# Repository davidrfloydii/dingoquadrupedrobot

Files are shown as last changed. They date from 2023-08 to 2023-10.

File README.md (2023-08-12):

# dingoquadrupedrobot
Modifications to Dingo Quadruped Robot

## [KiCAD PCB](https://github.com/davidrfloydii/dingoquadrupedrobot/tree/main/PCB)
Since the original files were Altium designer I recreated the board in KiCAD. Not 100% the same since it uses through hole components for the resistors and the diode.
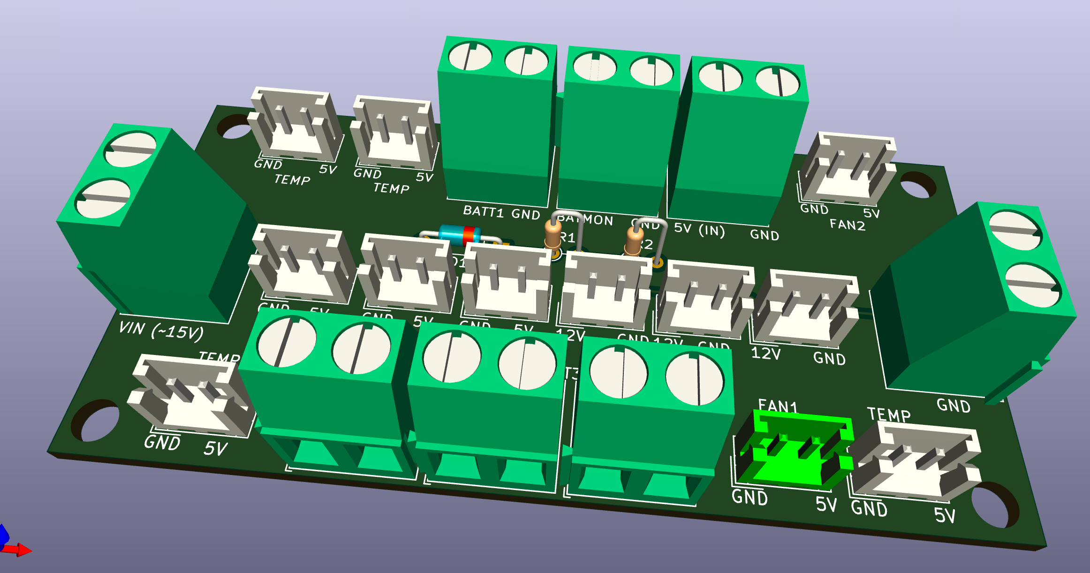
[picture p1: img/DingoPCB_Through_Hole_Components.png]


## [Modified Base Plate](https://github.com/davidrfloydii/dingoquadrupedrobot/blob/main/CAD/Dingo%20Base%20Plate.step)
Instead of ordering the Acrylic pieces you can try to print your own base plates. **Note**: This is not verified to hold up to the stresses of the robot. However if you decide to go this route be sure to use 100% infill for these pieces. Also blue the two halves together. Since it is printed this will have stand offs for 2 of the Raspberry Pi mounts and the rear of the front buck converter.
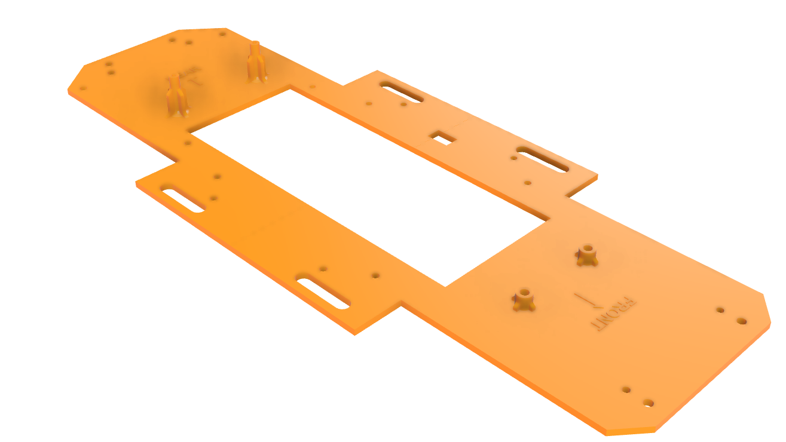
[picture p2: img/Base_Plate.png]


## [Redesigned LCD Bracket](https://github.com/davidrfloydii/dingoquadrupedrobot/blob/main/CAD/Rear%20LCD%20Holder%20v1.step)
For my build I decided to redesign the rear LCD holder so that screws and nuts weren't positioning. **Note** This still has not been tested and results may vary depending on your printer settings.
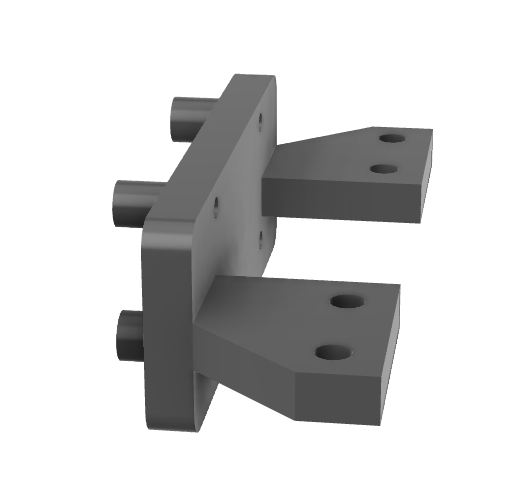
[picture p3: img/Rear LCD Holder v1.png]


## [New nose piece](https://github.com/davidrfloydii/dingoquadrupedrobot/blob/main/CAD/Dingo%20Front%20With%20Sonar%20v1.step)
The first modificaiton was to the front of the Dingo robot, it removes the plastic black eye and instead makes room for two HC-SR04 sensors.
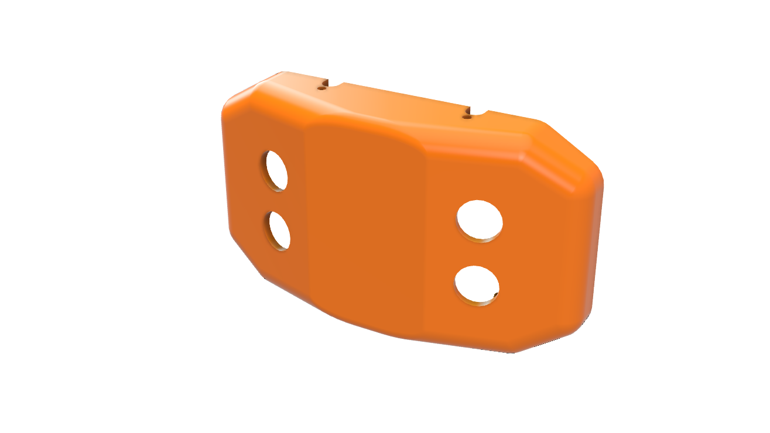
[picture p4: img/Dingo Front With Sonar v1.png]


## [New Fan Housing](https://github.com/davidrfloydii/dingoquadrupedrobot/blob/main/CAD/Fan%20Housings%20Builtin%20Hinge%20Pins.step)
This new fan housing creates tabs to act as the hinge. Reduces the number of pieces that need to be ordered.
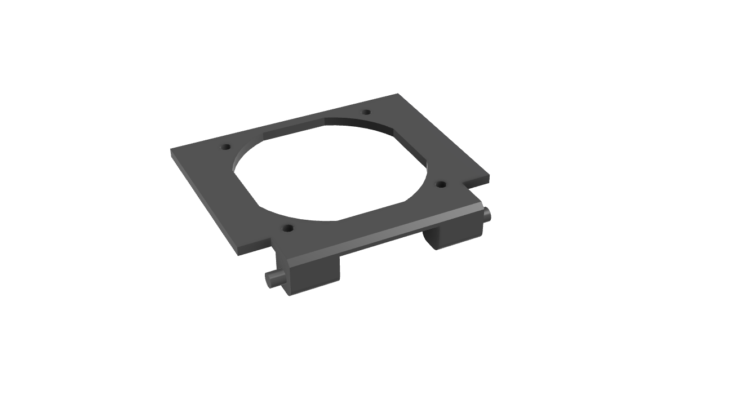
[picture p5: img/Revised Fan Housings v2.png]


## [Revised IMU Mount]((https://github.com/davidrfloydii/dingoquadrupedrobot/blob/main/CAD//Revised%20IMU%20Mount%20v4.step)
I updated the IMU mount because the version I ordered here in the US had slightly different pattern for mounting holes. Additionally the 3 digit display I ordered from Amazon also had slightly different mounting holes. If you are using the same components you can use this step file.
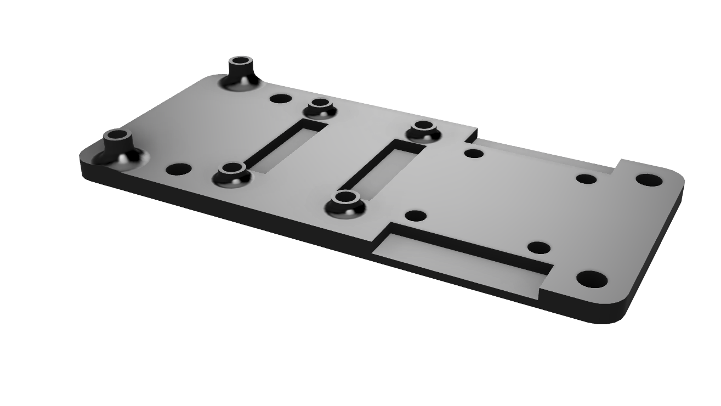
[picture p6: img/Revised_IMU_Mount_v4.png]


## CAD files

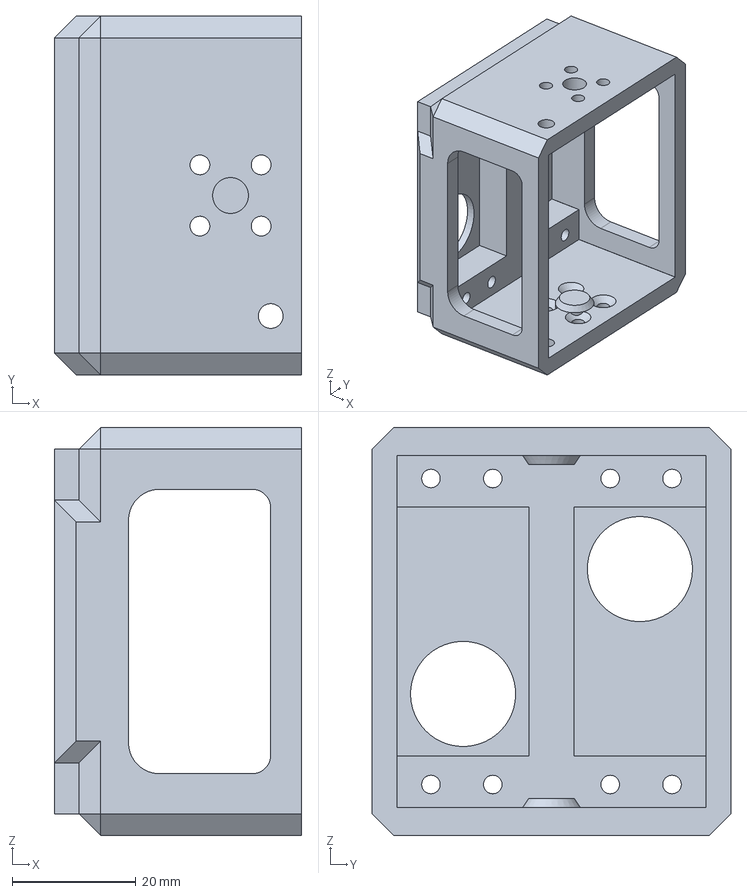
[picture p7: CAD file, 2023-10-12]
CAD/Modified Servo Carriers 01.step
40.0 x 58.0 x 66.0 mm

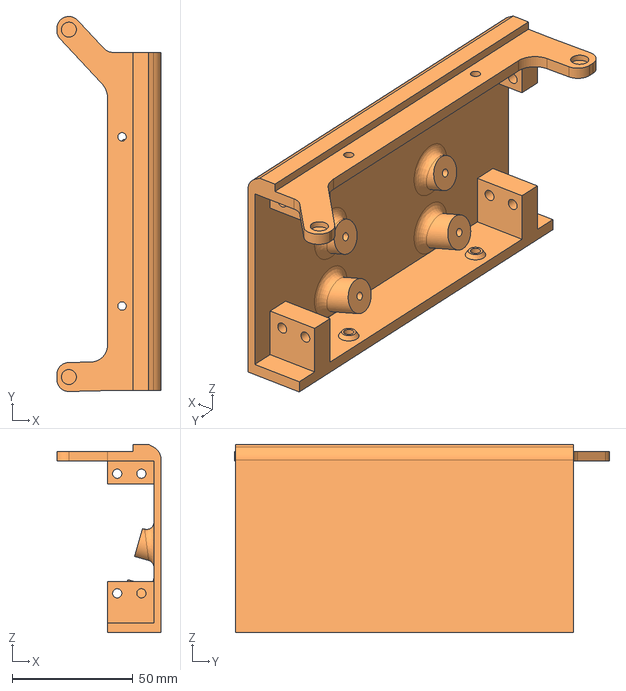
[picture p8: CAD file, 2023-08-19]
CAD/Revised Support PCA9685.step
43.2 x 155.2 x 77.9 mm

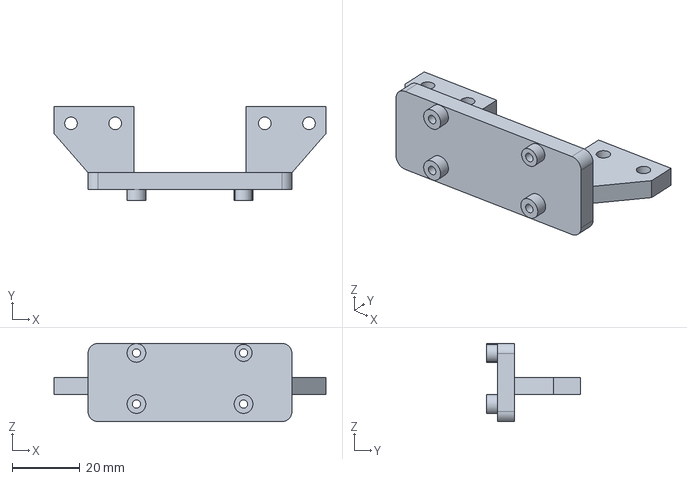
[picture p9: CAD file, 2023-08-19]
CAD/Rear LCD Holder.step
80.0 x 27.8 x 23.0 mm

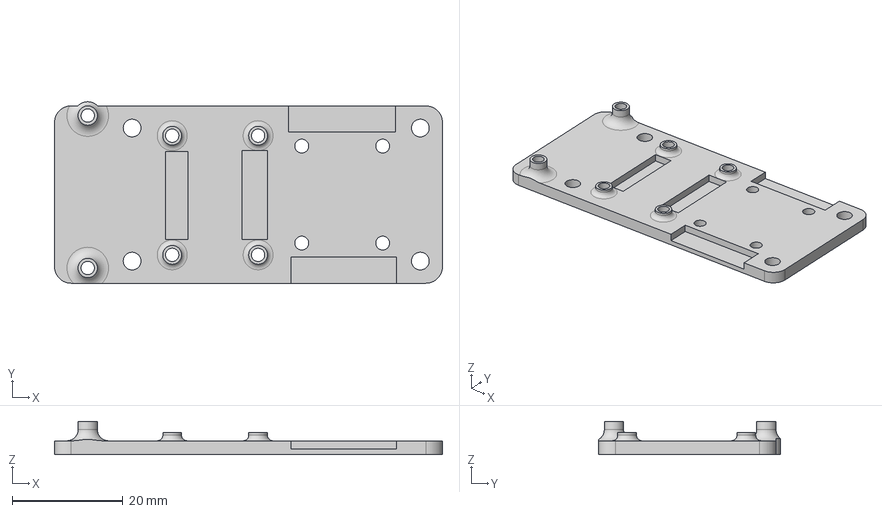
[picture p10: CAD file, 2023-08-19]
CAD/Revised IMU Mount.step
70.0 x 32.7 x 6.00 mm

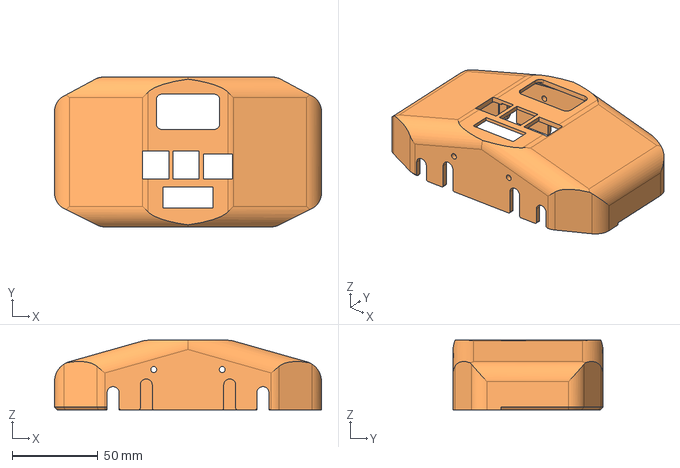
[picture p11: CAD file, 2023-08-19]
CAD/Joined Rear Housing.step
156.0 x 87.5 x 40.6 mm

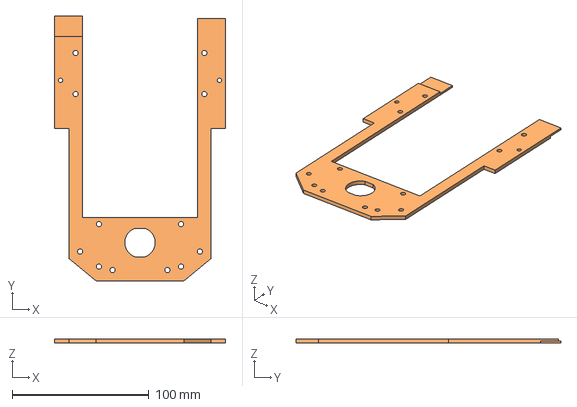
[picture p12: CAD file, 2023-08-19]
CAD/Revised Top Plate 02.step
125.0 x 193.5 x 3.00 mm

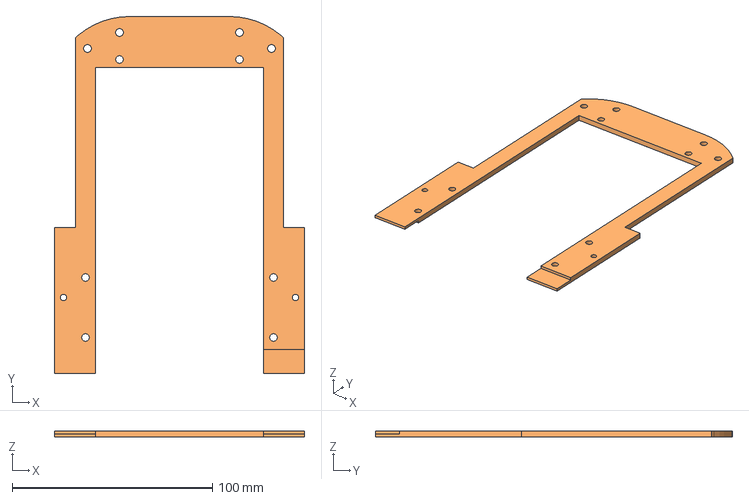
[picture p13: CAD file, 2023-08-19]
CAD/Revised Top Plate 01.step
125.0 x 178.5 x 3.00 mm

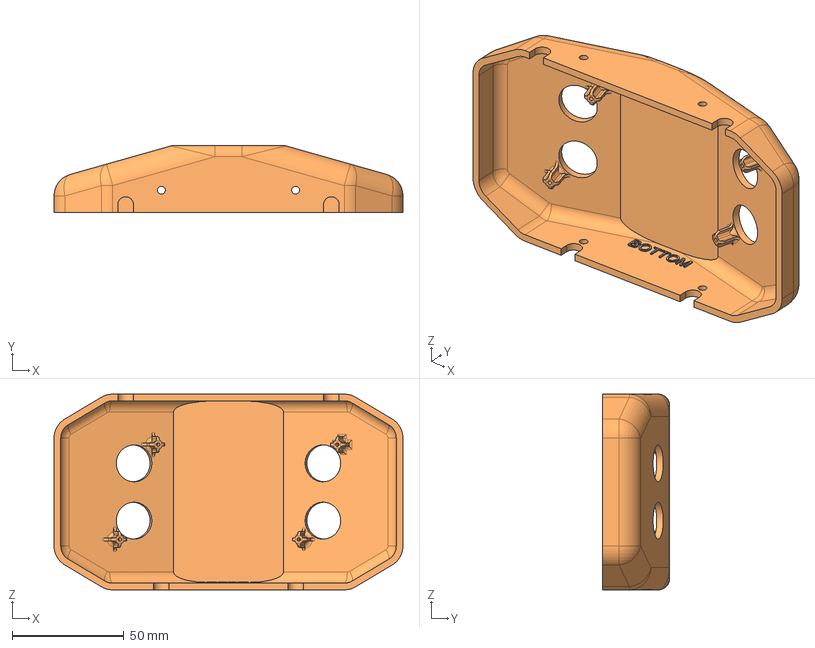
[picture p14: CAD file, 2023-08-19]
CAD/Dingo Front With Sonar.step
156.0 x 30.0 x 87.5 mm

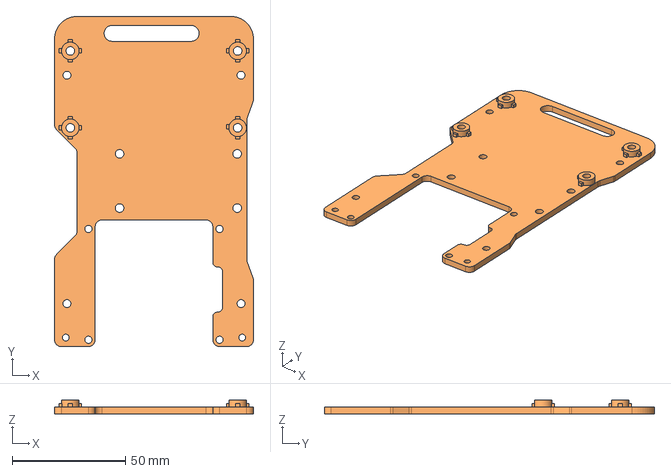
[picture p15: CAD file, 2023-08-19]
CAD/Revised Board Support.step
88.0 x 146.0 x 6.00 mm

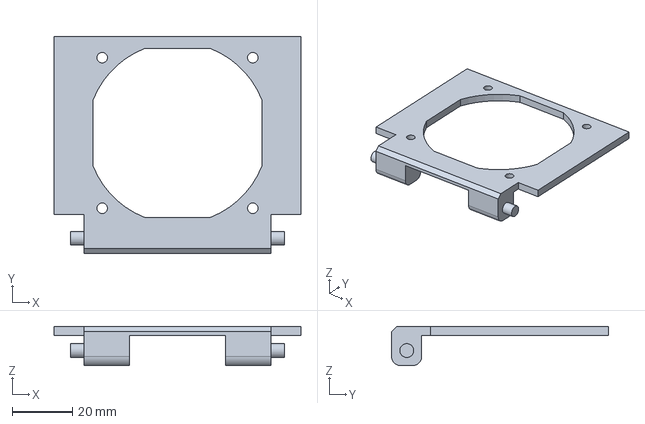
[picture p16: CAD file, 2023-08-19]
CAD/Revised Fan Housings.step
82.0 x 72.0 x 13.0 mm

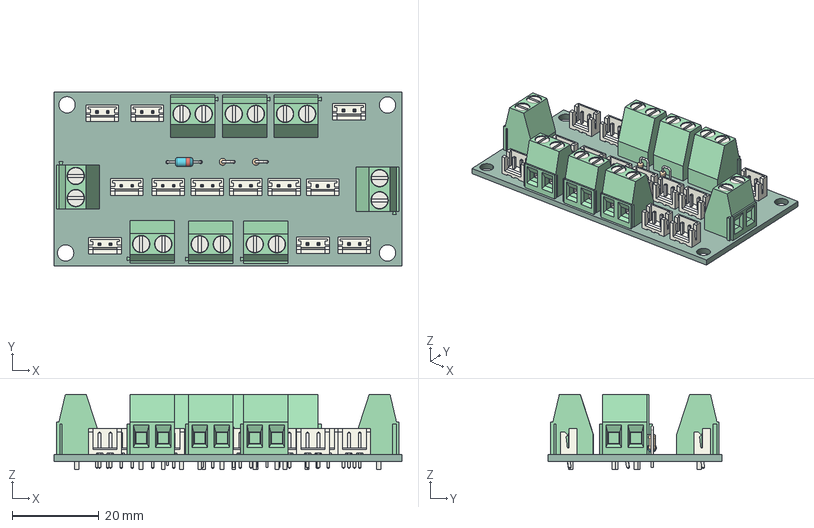
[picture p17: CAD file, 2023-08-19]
CAD/DingoPCB.step
80.0 x 40.0 x 17.3 mm
PCB

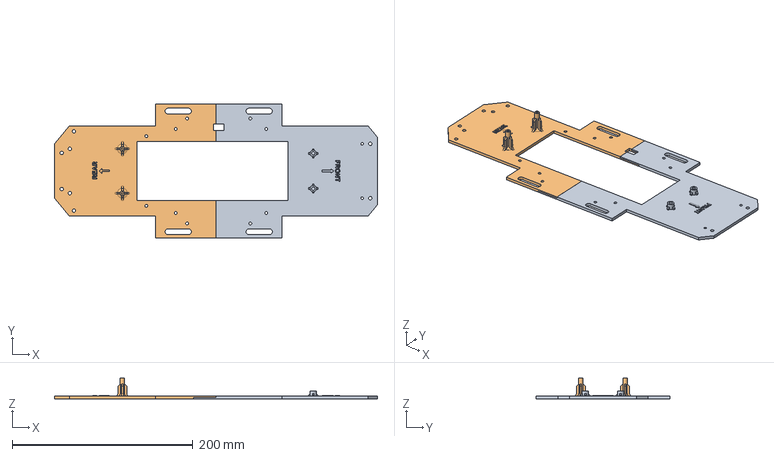
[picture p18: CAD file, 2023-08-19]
CAD/Dingo Base Plate.step
357.0 x 148.4 x 23.0 mm
Torso base plate
Back

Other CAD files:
CAD/Modified Servo Carriers 02.step
CAD/Fan Housings Builtin Hinge Pins.step
CAD/Revised IMU Mount v4.step
CAD/Rear LCD Holder v1.step

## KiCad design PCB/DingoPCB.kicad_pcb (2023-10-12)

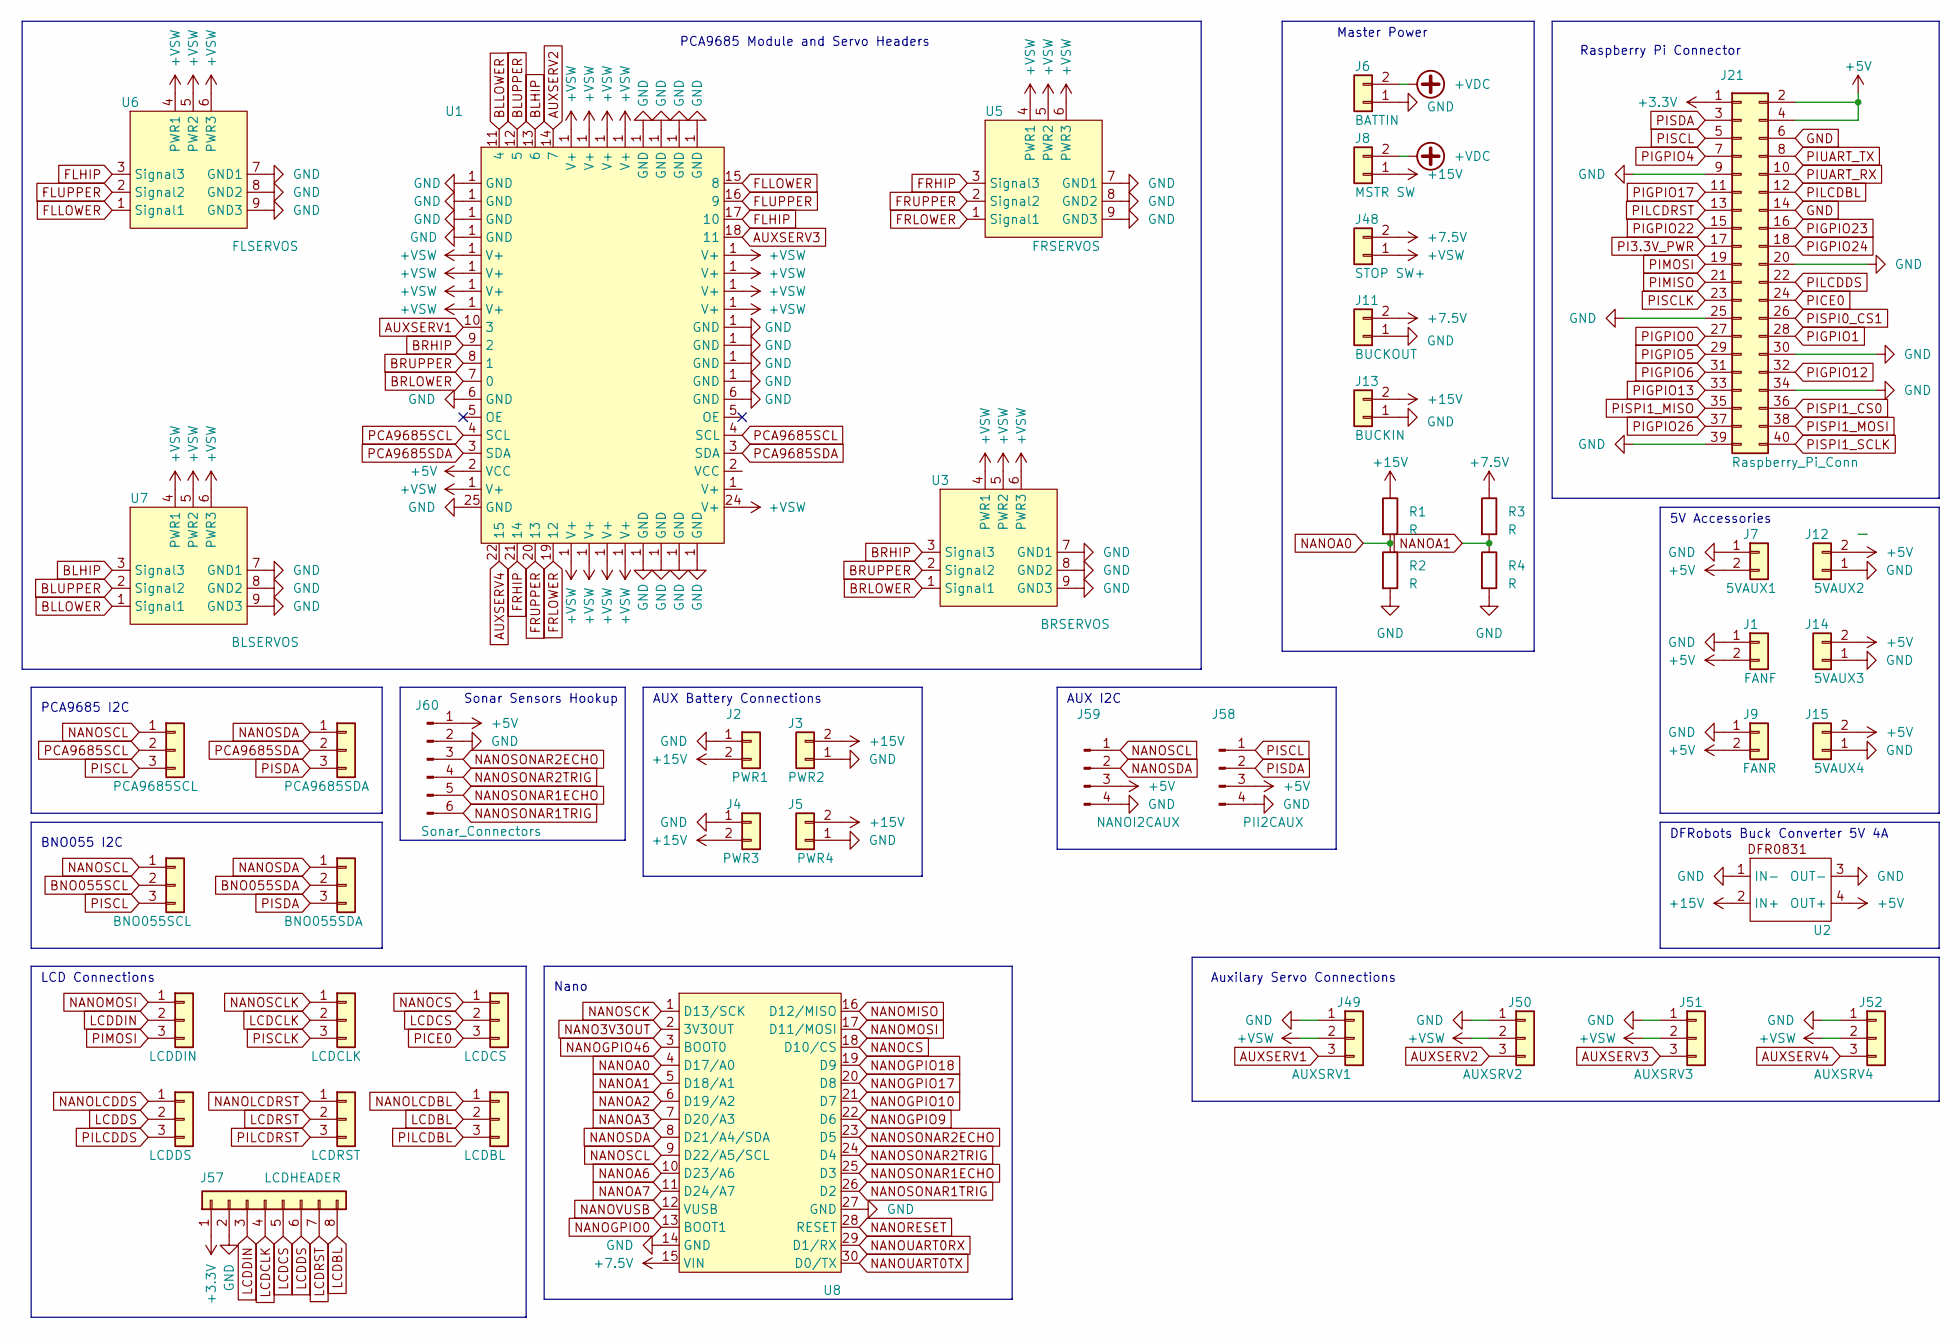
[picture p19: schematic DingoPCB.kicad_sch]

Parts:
J1: FANF; JST_EH_B2B-EH-A_1x02_P2.50mm_Vertical
J2: PWR1; TerminalBlock_Phoenix_MKDS-1,5-2-5.08_1x02_P5.08mm_Horizont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
J3: PWR2; TerminalBlock_Phoenix_MKDS-1,5-2-5.08_1x02_P5.08mm_Horizont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
J4: PWR3; TerminalBlock_Phoenix_MKDS-1,5-2-5.08_1x02_P5.08mm_Horizont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
J5: PWR4; TerminalBlock_Phoenix_MKDS-1,5-2-5.08_1x02_P5.08mm_Horizont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
J6: BATTIN; TerminalBlock_Phoenix_MKDS-1,5-2-5.08_1x02_P5.08mm_Horizont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
J7: 5VAUX1; JST_EH_B2B-EH-A_1x02_P2.50mm_Vertical
J8: MSTR SW; TerminalBlock_Phoenix_MKDS-1,5-2-5.08_1x02_P5.08mm_Horizont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
J9: FANR; JST_EH_B2B-EH-A_1x02_P2.50mm_Vertical
J10: PCA9685SDA; PinHeader_1x03_P2.54mm_Vertical
J11: BUCKOUT; TerminalBlock_Phoenix_MKDS-1,5-2-5.08_1x02_P5.08mm_Horizont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
J12: 5VAUX2; JST_EH_B2B-EH-A_1x02_P2.50mm_Vertical
J13: BUCKIN; TerminalBlock_Phoenix_MKDS-1,5-2-5.08_1x02_P5.08mm_Horizont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
J14: 5VAUX3; JST_EH_B2B-EH-A_1x02_P2.50mm_Vertical
J15: 5VAUX4; JST_EH_B2B-EH-A_1x02_P2.50mm_Vertical
J16: BNO055SDA; PinHeader_1x03_P2.54mm_Vertical
J17: BNO055SCL; PinHeader_1x03_P2.54mm_Vertical
J18: LCDDS; PinHeader_1x03_P2.54mm_Vertical
J19: LCDRST; PinHeader_1x03_P2.54mm_Vertical
J20: LCDBL; PinHeader_1x03_P2.54mm_Vertical
J21: Raspberry_Pi_Conn; PinHeader_2x20_P2.54mm_Vertical
J48: STOP SW+; TerminalBlock_Phoenix_MKDS-1,5-2-5.08_1x02_P5.08mm_Horizont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
J49: AUXSRV1; PinHeader_1x03_P2.54mm_Vertical
J50: AUXSRV2; PinHeader_1x03_P2.54mm_Vertical
J51: AUXSRV3; PinHeader_1x03_P2.54mm_Vertical
J52: AUXSRV4; PinHeader_1x03_P2.54mm_Vertical
J53: PCA9685SCL; PinHeader_1x03_P2.54mm_Vertical
J54: LCDDIN; PinHeader_1x03_P2.54mm_Vertical
J55: LCDCLK; PinHeader_1x03_P2.54mm_Vertical
J56: LCDCS; PinHeader_1x03_P2.54mm_Vertical
J57: LCDHEADER; PinHeader_1x08_P2.54mm_Horizontal
J58: PII2CAUX; JST_EH_B4B-EH-A_1x04_P2.50mm_Vertical
J59: NANOI2CAUX; JST_EH_B4B-EH-A_1x04_P2.50mm_Vertical
J60: Sonar_Connectors; JST_EH_B6B-EH-A_1x06_P2.50mm_Vertical
R1, R2, R3, R4: R; R_Axial_DIN0204_L3.6mm_D1.6mm_P2.54mm_Vertical
U1: Adafruit PCA9685 rev C
U2: DFR0831
U3: BRSERVOS; Three_Servo_Footprint
U5: FRSERVOS; Three_Servo_Footprint
U6: FLSERVOS; Three_Servo_Footprint
U7: BLSERVOS; Three_Servo_Footprint
U8: Arduino_Nano_ESP32

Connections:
+3.3V: J21.1, J57.1
+5V: J1.2, J7.2, J9.2, J12.2, J14.2, J15.2, J21.2, J21.4, J58.3, J59.3, J60.1, U1.2 (VCC), U2.4 (OUT+); also elsewhere on the board
+7.5V: J11.2, J48.2, R3.1, U8.15 (VIN)
+15V: J2.2, J3.2, J4.2, J5.2, J8.1, J13.2, R1.1, U2.2 (IN+)
+VDC: J6.2, J8.2
AUXSERV1: J49.3, U1.10 (3)
AUXSERV2: J50.3, U1.14 (7)
AUXSERV3: J51.3, U1.18 (11)
AUXSERV4: J52.3, U1.22 (15)
BLHIP: U1.13 (6), U7.3 (Signal3)
BLLOWER: U1.11 (4), U7.1 (Signal1)
BLUPPER: U1.12 (5), U7.2 (Signal2)
BNO055SCL: J17.2; also elsewhere on the board
BNO055SDA: J16.2; also elsewhere on the board
BRHIP: U1.9 (2), U3.3 (Signal3)
BRLOWER: U1.7 (0), U3.1 (Signal1)
BRUPPER: U1.8 (1), U3.2 (Signal2)
FLHIP: U1.17 (10), U6.3 (Signal3)
FLLOWER: U1.15 (8), U6.1 (Signal1)
FLUPPER: U1.16 (9), U6.2 (Signal2)
FRHIP: U1.21 (14), U5.3 (Signal3)
FRLOWER: U1.19 (12), U5.1 (Signal1)
FRUPPER: U1.20 (13), U5.2 (Signal2)
LCDBL: J20.2, J57.8
LCDCLK: J55.2, J57.4
LCDCS: J56.2, J57.5
LCDDIN: J54.2, J57.3
LCDDS: J18.2, J57.6
LCDRST: J19.2, J57.7
NANO3V3OUT: U8.2 (3V3OUT)
NANOA0: R1.2, R2.1, U8.4 (D17/A0)
NANOA1: R3.2, R4.1, U8.5 (D18/A1)
NANOA2: U8.6 (D19/A2)
NANOA3: U8.7 (D20/A3)
NANOA6: U8.10 (D23/A6)
NANOA7: U8.11 (D24/A7)
NANOCS: J56.1, U8.18 (D10/CS)
NANOGPIO0: U8.13 (BOOT1)
NANOGPIO9: U8.22 (D6)
NANOGPIO10: U8.21 (D7)
NANOGPIO17: U8.20 (D8)
NANOGPIO18: U8.19 (D9)
NANOGPIO46: U8.3 (BOOT0)
NANOLCDBL: J20.1
NANOLCDDS: J18.1
NANOLCDRST: J19.1
NANOMISO: U8.16 (D12/MISO)
NANOMOSI: J54.1, U8.17 (D11/MOSI)
NANORESET: U8.28 (RESET)
NANOSCK: U8.1 (D13/SCK)
NANOSCL: J17.1, J53.1, J59.1, U8.9 (D22/A5/SCL)
NANOSCLK: J55.1
NANOSDA: J10.1, J16.1, J59.2, U8.8 (D21/A4/SDA)
NANOSONAR1ECHO: J60.5, U8.25 (D3)
NANOSONAR1TRIG: J60.6, U8.26 (D2)
NANOSONAR2ECHO: J60.3, U8.23 (D5)
NANOSONAR2TRIG: J60.4, U8.24 (D4)
NANOUART0RX: U8.29 (D1/RX)
NANOUART0TX: U8.30 (D0/TX)
NANOVUSB: U8.12 (VUSB)
PCA9685SCL: J53.2, U1.4 (SCL)
PCA9685SDA: J10.2, U1.3 (SDA)
PI3.3V_PWR: J21.17
PICE0: J21.24, J56.3
PIGPIO0: J21.27
PIGPIO1: J21.28
PIGPIO4: J21.7
PIGPIO5: J21.29
PIGPIO6: J21.31
PIGPIO12: J21.32
PIGPIO13: J21.33
PIGPIO17: J21.11
PIGPIO22: J21.15
PIGPIO23: J21.16
PIGPIO24: J21.18
PIGPIO26: J21.37
PILCDBL: J20.3, J21.12
PILCDDS: J18.3, J21.22
PILCDRST: J19.3, J21.13
PIMISO: J21.21
PIMOSI: J21.19, J54.3
PISCL: J17.3, J21.5, J53.3, J58.1
PISCLK: J21.23, J55.3
PISDA: J10.3, J16.3, J21.3, J58.2
PISPI0_CS1: J21.26
PISPI1_CS0: J21.36
PISPI1_MISO: J21.35
PISPI1_MOSI: J21.38
PISPI1_SCLK: J21.40
PIUART_RX: J21.10
PIUART_TX: J21.8

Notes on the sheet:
Nano
PCA9685 I2C
5V Accessories
LCD Connections
AUX Battery Connections
PCA9685 Module and Servo Headers
AUX I2C
Sonar Sensors Hookup
Auxilary Servo Connections
Master Power
BNO055 I2C
DFRobots Buck Converter 5V 4A
Raspberry Pi Connector

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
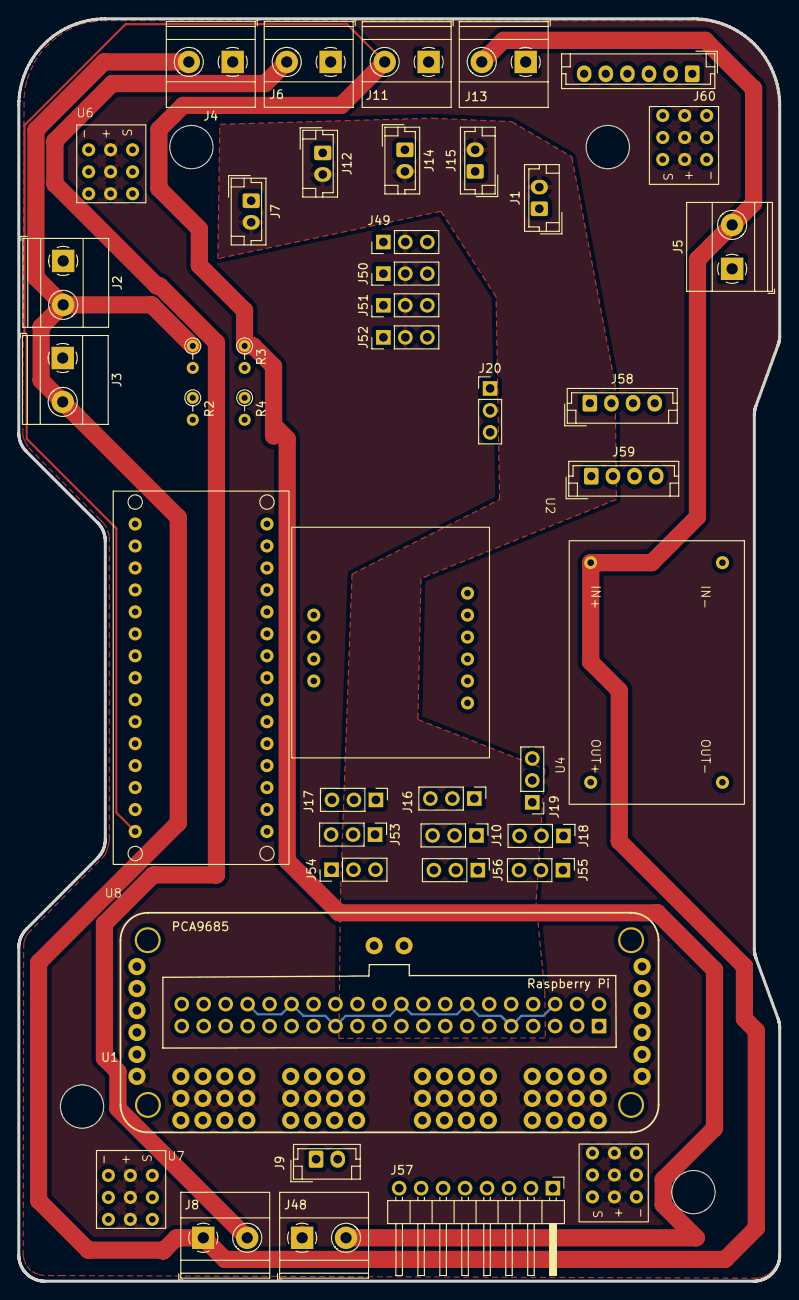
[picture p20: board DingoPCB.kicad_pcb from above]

Board: 4 copper layers, 88.0 x 146.0 mm, 46 parts (1 on the bottom side), 51 nets.

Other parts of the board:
U4: Adafruit BNO055

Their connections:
+5V: U4.1 (+5V); also elsewhere on the board
BNO055SCL: U4.5 (SCL); also elsewhere on the board
BNO055SDA: U4.4 (SDA); also elsewhere on the board

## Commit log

2023-08-05 Adding step file for updated nose
    This new nose piece is designed to have a HC-SR04 module on each of the angled sides of the front. The black center eye piece has been removed to make room.
    [Dingo Front With Sonar v1.step]
2023-08-07 Printable Version Base Plate
    The design calls for this piece to be cut in acrylic. I've cut the piece into two pieces then created overlap so that there is some strength where the pieces come together. Printed with ABS at 100% infill this seems to work. Won't know for sure until the robot is complete and have a chance to see how it holds up. May revised the design with additional support if needed. I prefer to print as much as possible not just for cost but also replacement parts.
    [Dingo Base Plate Printed.step]
2023-08-07 Fan holders with built in hinge pins
    The original design printed the fan holders with the assumption that another piece would be used to form the hinge. I am trying this to see if printing with the pins built in will fit nicely and hold up. My print is being done with ABS and 100% infill. Please use at your own risk. These may fail.
    [Fan Housings Builtin Hinge Pins.step]
2023-08-08 Top plate of robot split in half with overlap
    My printer was not large enough to print this in one piece. I modified the part to split it in half then overlap tabs on each side for a strong connection between the two pieces. If you want to glue 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
    [Revised Top Plate v1.step]
2023-08-08 Image of new fan housing design
    This is the design of the new fan housing
2023-08-09 Adding KiCAD for PCB
    [DingoPCB.kicad_pcb, DingoPCB.kicad_sch]
2023-08-09 Updates to masks on PCB
    [DingoPCB.kicad_pcb]
2023-08-09 Gerber files added
    [DingoPCB-B_Cu.gbr, DingoPCB-B_Mask.gbr, DingoPCB-B_Paste.gbr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]
2023-08-09 Updating image of PCB
2023-08-09 Updated PCB Export
2023-08-09 Updates to PCB for better readability
2023-08-09 Moved terminals closer together
    [DingoPCB.kicad_pcb]
2023-08-09 Updated 3D image of PCB
2023-08-10 Adding redesigned LCD holder
    [Rear LCD Holder v1.step]
2023-08-11 Updated PCB exports and rear screen holder
    [DingoPCB-B_Cu.gbr, DingoPCB-B_Mask.gbr, DingoPCB-B_Paste.gbr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]
2023-08-11 Updated base plate step file and image of new design.
    [Dingo Base Plate.step]
2023-08-11 Adding version of rear LCD mount that I am using
    [Rear LCD Holder v1.step]
2023-08-11 Adding link for base plate
2023-08-11 More link updates and removing old file
    [Dingo Base Plate Printed.step]
2023-08-12 Revised IMU mount for amazon parts
    [Revised IMU Mount v4.step]
2023-08-19 Latest revisions to all CAD and updated PCB
    [Dingo Base Plate.step, Dingo Front With Sonar v1.step, Dingo Front With Sonar.step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]
2023-10-12 Adding updated servo carriers
    [DingoPCB-B_Cu.gbr, DingoPCB-B_Mask.gbr, DingoPCB-B_Paste.gbr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]
